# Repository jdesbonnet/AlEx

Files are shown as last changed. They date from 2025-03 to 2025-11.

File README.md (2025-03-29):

# AlEx - Aluminium Extrusion related 3D printed parts library.

Library of 3D printed parts to aid construction projects using Aluminium (Aluminum) extrusions.

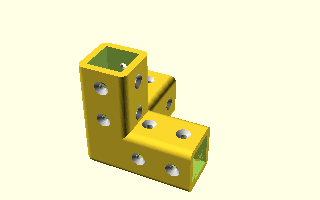
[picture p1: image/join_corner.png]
Example join fitting: corner join (3 axis orthogonal)


Status: this library is in early development (pre 1.0), so things are going to be in flux for 
months 2025-03 and 2025-04. This library is being developed with OpenSCAD software with the
Prusa Slicer to convert the STL output from OpenSCAD into gcode for my Prusa Mini+ printer.
I'm prining with PLA polymer.

Example of a 3 axis orthogonal corner join:

```
use <lib_alex.scad>
use <lib_screw.scad>
$fn = 60;

AlEx_corner_join(ALD=20, L=60, M=4, T=4);
```

Parameters: 

 * ALD:  Aluminium width mm (15 or 20, but no reason why other sizes won't work)
 * T:    Wall thickness mm
 * L:    Length of join arms mm.
 * M:    Screw diameter mm (eg 3 for M3).

These joins are designed to be used with DIN 965 (cross recessed countersunk flat head) screws together 
with aluminium extrusion T-nuts.

The screw length and/or join fitting wall thickness (T) must be chosen carefully so that the screw head is flush
with the outer surface. 

For example if using 2020 extrusion with 10mm DIN 965 M4 screws, then the wall
thickness (T) must be 4mm. If you get this wrong the screw will either protrude 
or will not be able to sink deep enough to engage with the T-nut thread. 

> [!TIP]
> Print one part first and check that the extrusion slots in snuggly and that the 
> screws properly engage with the T-nut and are flush with the surface when 
> tightened.

> [!TIP]
> You will need to use support structure (eneabled in the slicer software) and 
> thoroughly clean out that material before slotting in the extrusions.

## Corner join (3 axis orthogonal)

Print 8 of these to create a box structure.

Corner join (3 axis orthogonal)

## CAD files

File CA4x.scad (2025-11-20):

$fn = 60;
eps = 0.001;

CB42();

//translate([1,0,0]) rotate ([0,0,   0]) translate([-15,-15,0]) CB42();
//translate([-1,0,0]) rotate ([0,0,  180]) translate([-15,-15,0]) CA42();

//translate([36,0,0]) rotate ([0,0,   0]) translate([-15,-15,0]) CA42();
//translate([34,0,0]) rotate ([0,0,  180]) translate([-15,-15,0]) CA42();

     //translate([-6,6,6]) cube ([30,30,8]);
    
/**
 *
 * Right-angle corner join for 2020 aluminium extrusion (Bosch standard profile
 * with 6mm groove). 
 *
 * The join requires 4 x countersuck flat head DIN965 M4 bolts length 10mm. 
 * Other standards might work provided the space for the bolt head is compatible
 * (ie a cone with d1=4.6mm to d2=7.5mm with head height 2.2mm).
 *
 * Also required are 4 x M4 T-nuts compatible with 6mm groove 2020 extrusions.
 *
 * Use instruction: I
 * 
 * Insert 4 x M4 bolts into the join until the tread protrudes
 * out the far side. Twist a T-nut onto the protruded thread and tighten so that
 * the bolt head sits snugly in the countersunk cavity (this is necessary to 
 * allow bolts in the orthogonal direction to be inserted). Now align the
 * T-nuts so that that long axis of the nut can be directly inserted into the
 * 2020 groove. 
 *
 * Once the join is in place, with the bolts slightly tighted, before fully tightning 
 * the bolts, first loosen the bolt by 3 turns. This will almost (but not fully) 
 * retract the bolt from the T-nut allowing it to rotate in the groove. Now fully
 * tighten. The T-nut should now rotate until its axis is perpendicular to the groove 
 * - this provides the optimum grip. Note: the T-nut is designed with rounded corners
 * to allow it to rotate to this orientation but not beyond.
 *
 * If possible visually inspect the T-nut to ensure that rotation has taken place.
 *
 * Alternativly if you have access to an open end of the 2020
 * extrusion you can align the T-nuts so that the long axis is perpendicular
 * to the groove. Before insertion tighten bolt/nut to 'finger tight'. Slide the
 * join to where it's needed and then fully tighten the bolts.
 *
 * 
 * Notes about the slicing for 3D printer: 
 * This is tested with 0.6mm nozzel with 0.3mm layer height on
 * Prusa Mini+. Printed with PLA. Set vertical shells to 4 or more.
 * Since bolt heads / T-nuts will be applying significant compressive force along 
 * the direction of the bolt holes these structures should be made as strong
 * as possible for compression.
 *
 * TODO: current version is designed for DIN965 bolts. This may not be the best
 * choice for use with PLA 3D print. Considering DIN912 with a flat cylinder head
 * as alternative. If using DIN912, a 10mm bolt is too long. Maybe 
 
 * Part number:
 * C - corner join 
 * A - type A
 * 4 - M4 bolts
 * 2 - 20mm slot 6 aluminium profile
 */
module CA42 () {
    difference() {
    
        cube ([30,30,20]);
        translate([0,0,-eps]) rotate([0,0,45]) cube ([50,30,20+eps*3]);


        // Clear out material to make screw insertion easier (optional)
        // but likely to require support material.
        // Experimental. Use curved cutout to reduce need for support material.
        translate([30,0,10]) rotate([-90,0,45]) translate([0,0,20]) scale([2.2,1,1]) sphere (d=12);


        // Holes for M4 DIN965 10mm bolts d2 (head dia) = 7.5mm; k (head surface to thread start) = 2.2mm
        //translate ([10,0-eps,10]) rotate([-90,0,0]) screwhole_DIN965();
        //translate ([20,0-eps,10]) rotate([-90,0,0]) screwhole_DIN965();
        //translate ([30,10-eps,10]) rotate([0,-90,0]) screwhole_DIN965();
        //translate ([30,20-eps,10]) rotate([0,-90,0]) screwhole_DIN965();

        translate ([10,0-eps,10]) rotate([-90,0,0]) screwhole_DIN912();
        translate ([20,0-eps,10]) rotate([-90,0,0]) screwhole_DIN912();
        translate ([30,10-eps,10]) rotate([0,-90,0]) screwhole_DIN912();
        translate ([30,20-eps,10]) rotate([0,-90,0]) screwhole_DIN912();
        
        
        // Part number 'etched' on top surface
        translate([7.5,2,0]) translate([0,0,20-0.3]) linear_extrude(0.6) text("CA42", size=6);

    }
    


    // Slot notches: these should squeeze into the aluminium grooves and provide extra
    // ridgitity of the joint in out-of-plane forces/torques. Ie forces where there is a 
    // 'z' component (if you consider the two struts being joing being on the x and y axis).
    //
    // Groove width measured at 6.27mm, setting at 6.30. When screws tighten this should sqeeze
    // these notches in. I'm hoping to get away with printing this without hoverhang supports.
    // Update: these notches work. Works well at nw=6.3mm wide, but I think it can be slightly wider.
    // Update: no at 6.6mm it prevented the join from being flush with the aluminium surface. Stick
    // with 6.3mm.
    nw = 6.3;
    translate ([0,-1,(20-nw)/2]) cube ([4,1,nw]);
    translate ([26,-1,(20-nw)/2]) cube ([4,1,nw]);

    translate ([30,0,(20-nw)/2]) cube ([1,4,nw]);
    translate ([30,26,(20-nw)/2]) cube ([1,4,nw]);





    // Cavity for DIN965 M4 bolt including the conical head. 
    module screwhole_DIN965() {
        // Bolt shaft
        translate([0,0,0]) cylinder (d=4.6,h=3+eps);
        
        // Conical counter-sink head
        translate([0,0,3]) cylinder (d1=4.6, d2=7.5, ,h=2.2);
        translate([0,0,5.2]) cylinder (d=7.5, ,h=20);
    }

    // Cavity for DIN912 M4 bolt. M4 bolt head height is 4mm.
    module screwhole_DIN912() {
        // Bolt shaft
        translate([0,0,0]) cylinder (d=4.6,h=5+eps);
        translate([0,0,3]) cylinder (d=7.2, ,h=40);
    }
}

/**
 * Similar to CA42 except designed for DIN912 10mm bolts. Due to the bolt head height
 * it the bolt hole spacing had to be increased necessiating the increase in size to
 * a 40x40x20mm clipped along the diagnal.
 *
 * Idea: tiny hole to allow verification if T-nut has properly engaged with groove.
 */

module CB42 () {
    

        //translate([0,0,10]) rotate([-90,0,45]) translate([20*sqrt(2),0,00]) scale([30*sqrt(2) * 1.0,12,10]) sphere (d=1);

    difference() {
    
        cube ([40,40,20]);
        translate([0,0,-eps]) rotate([0,0,45]) cube ([60,30,20+eps*3]);


        // Clear out material to make screw insertion easier (optional)
        // but likely to require support material.
        // Experimental. Use curved cutout to reduce need for support material.
        translate([0,0,10]) rotate([-90,0,45]) translate([20*sqrt(2),0,00]) scale([24*sqrt(2) * 1.0,14,20]) sphere (d=1);


        // Holes for M4 DIN965 10mm bolts d2 (head dia) = 7.5mm; k (head surface to thread start) = 2.2mm
        //translate ([10,0-eps,10]) rotate([-90,0,0]) screwhole_DIN965();
        //translate ([20,0-eps,10]) rotate([-90,0,0]) screwhole_DIN965();
        //translate ([30,10-eps,10]) rotate([0,-90,0]) screwhole_DIN965();
        //translate ([30,20-eps,10]) rotate([0,-90,0]) screwhole_DIN965();

        translate ([40-15,0-eps,10]) rotate([-90,0,0]) screwhole_DIN912();
        translate ([40-30,0-eps,10]) rotate([-90,0,0]) screwhole_DIN912();
        
        translate ([40,15-eps,10]) rotate([0,-90,0]) screwhole_DIN912();
        translate ([40,30-eps,10]) rotate([0,-90,0]) screwhole_DIN912();
        
        
        // Part number 'etched' on top surface
        translate([10,2,0]) translate([0,0,20-0.3]) linear_extrude(0.6) text("CB42", size=6);

    }
    
    // Show bolts
    //translate ([40-15,6,10])   rotate([-90,0,0]) bolt_DIN912(m=4,h=10);
    //translate ([40-30,6,10])   rotate([-90,0,0]) bolt_DIN912(m=4,h=10);


    // Slot notches: these should squeeze into the aluminium grooves and provide extra
    // ridgitity of the joint in out-of-plane forces/torques. Ie forces where there is a 
    // 'z' component (if you consider the two struts being joing being on the x and y axis).
    //
    // Groove width measured at 6.27mm, setting at 6.30. When screws tighten this should sqeeze
    // these notches in. I'm hoping to get away with printing this without hoverhang supports.
    // Update: these notches work. Works well at nw=6.3mm wide, but I think it can be slightly wider.
    // Update: no at 6.6mm it prevented the join from being flush with the aluminium surface. Stick
    // with 6.3mm.
    nw = 6.3;
    translate ([0,-1,(20-nw)/2]) cube ([4,1,nw]);
    translate ([36,-1,(20-nw)/2]) cube ([4,1,nw]);

    translate ([40,0,(20-nw)/2]) cube ([1,4,nw]);
    translate ([40,36,(20-nw)/2]) cube ([1,4,nw]);


    // Cavity for DIN912 M4 bolt. M4 bolt head height is 4mm.
    module screwhole_DIN912() {
        // Bolt shaft
        translate([0,0,0]) cylinder (d=4.6,h=15+eps);
        translate([0,0,6]) cylinder (d=7.4, ,h=40);
    }
    
    module bolt_DIN912(m=4,h=10) {
        dk=7;
        k=4;
        ds=m;
        color([0.4,0.4,0.4]) {
        cylinder(d=dk,h=k);
        translate([0,0,-h]) cylinder(d=ds,h=h);
        }
    }
    
}

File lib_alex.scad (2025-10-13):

/** 
 * Library for aluminium extrusion joins and related parts.
 * Currently supports standard 1515 and 2020 extrusions.
 *
 * ALD:  Aluminium width mm (15 or 20, but no reason why other sizes won't work)
 * T:    Wall thickness
 * L:    Length of join arms.
 * M:    Screw diameter mm (eg 3 for M3).
 * 
 * ex_center_crew_hole : boolean flag to indicate if there should be a hole for a 
 *                       screw that goes down the centre of the extrusion
 * Joe Desbonnet
 * 2025-03-28
 */
 
 
use <lib_screw.scad>; 
 
/**
 * Holes to allow T-nuts to be used to secure the aluminium extrusion to the join.
 * 
 **/ 
module AlEx_screw_holes(ALD=15,T=3,M=4,ex_center_screw_hole) {
    eps = 0.001;
    
    L = ALD + T*2 + eps*2;
    
    start = ex_center_screw_hole ? 0 : 1;
    
    for (o = [-1,1]) {
    for (i = [start : 3]) {

        
        //translate([0, 0, ALD*i]) rotate([0,90,0]) translate([0,0,-L]) cylinder(d=M,h=L*3);
        translate([0, 0, ALD*i]) rotate([0,90,0]) translate([0,0,-ALD/2 -T-eps]) m_screw(d=M,h=L,orientation=o,slot=0);

        //translate([0, ALD*i, 0]) rotate([0,90,0]) translate([0,0,-L]) cylinder(d=M,h=L*3);
        translate([0, ALD*i, 0]) rotate([0,90,0])  translate([0,0,-ALD/2 -T-eps]) m_screw(d=M,h=L,orientation=o,slot=0);

        
        //translate([0, 0, ALD*i]) rotate([-90,0,0]) translate([0,0,-L]) cylinder(d=M,h=L*3);
        translate([0, 0, ALD*i]) rotate([-90,0,0]) translate([0,0,-ALD/2 -T-eps]) m_screw(d=M,h=L,orientation=o,slot=0);

        //translate([ALD*i, 0, 0]) rotate([-90,0,0]) translate([0,0,-L]) cylinder(d=M,h=L*3);
        translate([ALD*i, 0, 0]) rotate([-90,0,0]) translate([0,0,-ALD/2 -T-eps]) m_screw(d=M,h=L,orientation=o,slot=0);

        //translate([0, ALD*i, 0]) rotate([0,0,0]) translate([0,0,-L]) cylinder(d=M,h=L*3);
        translate([0, ALD*i, 0]) rotate([0,0,0]) translate([0,0,-ALD/2 -T-eps]) m_screw(d=M,h=L,orientation=o,slot=0);


        //translate([ALD*i, 0, 0]) rotate([0,0,0]) translate([0,0,-L]) cylinder(d=M,h=L*3);
        translate([ALD*i, 0, 0]) rotate([0,0,0]) translate([0,0,-ALD/2 -T-eps]) m_screw(d=M,h=L,orientation=o,slot=0);
            
    }
}
}

/**
 * Subtract cavity in which the aluminium extrusion slots into.
 *
 * Observation: on first test print for 2020 extrusion, the cavity for the vertical (z axis) 
 * arm was perfect: 2020 extrusion slotted in with a little but not much friction. The other
 * two arms required chamfing the edges at the arm ends and it still required a lot of force
 * (enough to split on of the 3mm thick arms) to insert. Therefore it makes sense to add
 * a small extra clearance on those axes.
 **/
module AlEx_cavity(ALD=15,L=30,T=3) {
    eps = 0.001;
    rotate([0,0,0]) translate ([-ALD/2,-ALD/2,-ALD/2]) cube([ALD,ALD,L+eps]);
    
    // Extra clearance for X, Y axis (0.2mm)
    ALDX = ALD+0.2;
    rotate([-90, 0,0]) translate ([-ALDX/2,-ALDX/2,-ALD/2]) cube([ALDX,ALDX,L+eps]);
    rotate([  0,90,0]) translate ([-ALDX/2,-ALDX/2,-ALD/2]) cube([ALDX,ALDX,L+eps]);
}



/**
 * The sock material that forms each arm of the joint.
 */
module AlEx_corner_join_arm (ALD=15,L=30,T=2, label="?") {
	hull() {
		translate([-ALD/2,-ALD/2,0]) cylinder (r=T,h=L);
		translate([-ALD/2, ALD/2,0]) cylinder (r=T,h=L);
		translate([ ALD/2,-ALD/2,0]) cylinder (r=T,h=L);
		translate([ ALD/2, ALD/2,0]) cylinder (r=T,h=L);
	}
    
    //translate([-ALD/2-1.4, -ALD/4, ALD+T*6])  linear_extrude(400) rotate ([0,90,0]) offset(r=0.01) text (label,size=10,halign="center");
}


/**
 * 3 axis 90 degree join. One arm in each of x, y, z axis. For corner
 * of rectangular box.
 */
module AlEx_corner_join (ALD=15, L=30,M=4,T=3,ex_center_screw_hole=false) {
	eps = 0.001;
    
	difference() {
        
		// This is the stock from which we will subtract from
		union () {
			rotate ([0,0,0])   translate([0,0,-ALD/2]) AlEx_corner_join_arm(ALD,L,T,"Z");
			rotate ([-90,0,0]) translate([0,0,-ALD/2]) AlEx_corner_join_arm(ALD,L,T,"Y");
			rotate ([ 0,90,0]) translate([0,0,-ALD/2]) AlEx_corner_join_arm(ALD,L,T,"X");
			translate([-ALD/2,-ALD/2,-ALD/2]) sphere(r=T);// round the sharp corner
		}
        
		// Remove cavity for Al extrusion
		AlEx_cavity(ALD,L,T);

		// Drill out screw holes
		AlEx_screw_holes(ALD,T,M,ex_center_screw_hole);
	}

}

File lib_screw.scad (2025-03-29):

/**
 * Generic metric M series counter sunck screw (flat head).
 * Length (h) is from the flat head surface to the tip of the
 * threaded shaft.
 *
 * With counter sunk screws (flat head intended to be flush with surface) length of screw
 * includes the head. Lengh of head (k) in this table:
 * https://www.fasteners.eu/standards/din/965/
 *
 * Threads are not rendered.
 *
 * For M3 k=1.65mm
 *
 * orientation =  1    : head at z=0
 * orientation = -1    : orientated so that head at z=h
 *
 * Joe Desbonnet
 * 2025-03-28
 */
module m_screw(d=3,h=10,orientation=1,slot=1) {
	
	// Screw head and screw driver slot
	color([0.8,0.8,0.8]) {

		if (orientation == 1) {
			difference () {
				union() {
					cylinder (d=d,h=h);           // Main screw shaft
					cylinder (d1=d*2,d2=d,h=1.65);   // Conical screw head
				}
				if (slot) {
					translate ([-d,-0.5,-0.1]) cube([d*2,1,1.1]); // Screw driver slot
				}
			}
		} else {
			difference () {
				union() {
					cylinder (d=d,h=h);           // Main screw shaft
					translate ([0,0,h-2]) cylinder (d1=d,d2=d*2,h=2);   // Conical screw head
				}
				if (slot) {
					translate ([-d,-0.5,h-1]) cube([d*2,1,1.1]); // Screw driver slot
				}
			}
		}

	}

	// Label screw
	if (slot) {
	color([0.8,0.8,0.8]) translate ([0,-1.2,0.4]) text(str("M",d,"x",h),size=0.5,halign="center");
	}
}


/**
 * Spacer or washer
 * id = inner diameter
 * od = outer diameter
 * h = thickness
 */
module spacer (od,id,h) {
	difference() {
		cylinder(d=od,h=h);
		translate([0,0,-1]) cylinder(d=id,h=h+2);
	}
}

module spacer_square (od=8,id=6,h=5) {
	r=1;
	difference () {
		//translate([-od/2,-od/2,0]) cube ([od,od,h]);
		hull() {
			translate([-od/2+r,-od/2+r,0]) cylinder(d=r*2,h=h);
			translate([ od/2-r,-od/2+r,0]) cylinder(d=r*2,h=h);
			translate([ od/2-r, od/2-r,0]) cylinder(d=r*2,h=h);
			translate([-od/2+r, od/2-r,0]) cylinder(d=r*2,h=h);
		}
		translate([-id/2,-id/2,-1]) cube ([id,id,h+2]);
	}
}

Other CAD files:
join_corner_2020.scad

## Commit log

2025-10-04 2020 corner cube connector
    [join_corner_2020.scad]
2025-10-13 alternative corner join
    [join_corner_2020_B.scad]
2025-10-13 no comment
    [join_corner_2020_B.scad]
2025-10-13 rename corner join
    [CA4x.scad, lib_alex.scad]
2025-10-14 updates to 2020 join part
    [CA4x.scad]
2025-11-08 version that supports cylindrical head DIN912 bolts
    [CA4x.scad]
2025-11-09 0.2mm extra space for DIN912 bolt head
    [CA4x.scad]
2025-11-20 add comments
    [CA4x.scad]
